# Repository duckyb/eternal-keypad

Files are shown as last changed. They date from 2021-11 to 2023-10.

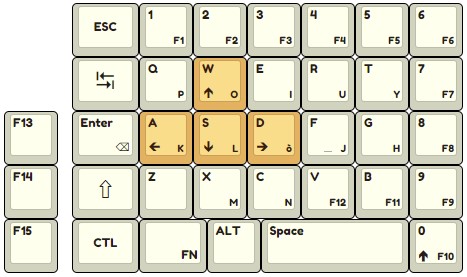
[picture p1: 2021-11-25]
gallery/default-layout.jpg

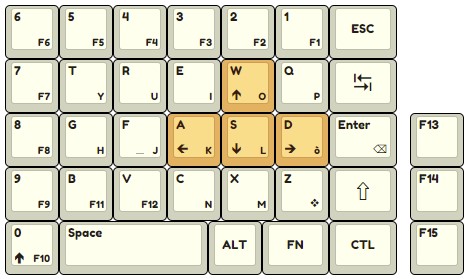
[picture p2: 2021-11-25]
gallery/lefty-layout.jpg

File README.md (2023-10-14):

# eternal_keypad_logo ETERNAL Keypad
ek-preview-rounded

<div class="shields">
  <a href="https://github.com/duckyb/eternal-keypad/releases">
    
    
  </a>
  
  <a href ="https://discord.gg/3erEKm3uht">
    
  </a>
</div>

### Sponsors

<span class="sponsors">
  <a href="https://shop.beekeeb.com/product/eternal-keypad-kit/">
    
  </a>
  <a href="https://www.pcbway.com/project/shareproject/ETERNAL_Keypad_5c58c0de.html">
    
  </a>
</span>
<div><sub>By purchasing from PCBWay I receive a percentage of the transaction</sub></div>

## Scope of the project

Eternal Keypad is an **open-source input device for gaming** that can be assembled for **both right and left hand mouse users**.

Historically there has been a scarcity of input devices for people that use their keyboard with their right hand and the mouse with the left, forcing some people to place their right hand in uncomfortable positions and/or requiring heavy remapping of in-game controls.
This device aims to fill this gap in the market that companies don't care about because the target is too small to turn a profit.

The device is Pro-micro compatible, so it's easier to build and source components.

## Features

⭕ Standard layout in a half-size form factor (all your keys are still there!)  
⭕ Ortholinear/grid layout for additional comfort  
⭕ Bluetooth support (nice!nano, battery, ZMK, power switch)  
⭕ Hotswap with Kailh Sockets  
⭕ RGB Underglow  
⭕ 3 macro buttons  
⭕ Easy to build  
⭕ Files for FR4 or laser cut plate case included  

## How can I make this?

<a href="https://youtu.be/vkTpa7AnWUo" target="_blank">
  
</a>

### Components list (latest PCB version)

#### For the Keyboard (required)

- 1× [ETERNAL Keypad PCB](https://github.com/duckyb/eternal-keypad/releases/latest)
- 36× through-hole or surface-mount diodes. (I use "1N4148 CDIL" from tme.eu)
- 36× MX style switches
- 36× Kailh Hotswap Sockets
- 1× Stabilizer (2u)
- 36× Keycaps (The set pictured above is "Honey & Milk XDA")
- 1× Microcontroller (Pro-micro or equivalent)

Optionals:
- 8× WS2812B RGB LEDs
- 1× Slider switch (for wireless)
- 1× LiPo battery (type: 301230, for wireless)

#### For the case (recommended)

- 1× [ETERNAL Keypad switch plate & bottom plate](https://github.com/duckyb/eternal-keypad/releases/latest)
  - If you want to have underglow RGB you should order a laser-cut bottom plate from acrylic, using the included `.dxf` file. If you don't care about underglow you can get an FR4 bottom plate PCB using the gerber file.
- 8× M2 Screws (I use "1154095 BOSSARD" from tme.eu)
- 4× M2 standoffs (diameter: 3mm, length: 8mm)
- 4× Rubber bump-on feet

### Buy as a DIY Kit

It might be more convenient to purchase this project as a kit, check out the [vendors page](./vendors.md).

## FAQ

Check the [dedicated page](./FAQ.md)

## Firmware

<a href="https://github.com/qmk/qmk_firmware/tree/master/keyboards/eternal_keypad" target="_blank">
  
</a>
<a href="https://www.caniusevia.com/">
  
</a>
<a href="https://zmk.dev/">
  
</a>

You can find firmwares in the [release section](https://github.com/duckyb/eternal-keypad/releases/latest), ready to download and flash.
If you want to customize them, you can do so using QMK, ZMK or VIA.

eternal_keypad

Note:
- The "A" and "D" keys are not mirrored to avoid inverting movement controls with default key-bindings.
- The "FN" key is used to access the missing half of the keyboard
- Holding the 0 key turns WASD into arrow keys

## Additional Resources

- 3D Printed case by chewiedies → [v4](https://www.thingiverse.com/thing:5329104), [v5, and v6](https://www.printables.com/model/290027-eternal-keypad-v12-gasket-mount-case-w-optional-te)

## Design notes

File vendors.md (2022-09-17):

# Vendors

This is a list of vendors that sell EK

| Store | Warehouse Location | Type | Approx. Price |
| :---: | :---: | :---: | :--: |
| [Beekeeb](https://shop.beekeeb.com/product/eternal-keypad-kit/) | Hong Kong | DIY Kit | $ 45.00 |
| [CustomKBD](https://customkbd.com/products/eternal-keypad-kit) | Australia | DIY Kit | $ 32.00 |
| [KEEBD](https://keebd.com/products/eternal-keypad-keyboard-kit) | Australia | DIY Kit | $ 40.00 |
| [PMM](https://pmm.gg/products/p-k-f-1) | Germany | Fully Assembled | € 300.00 |

💙 If you wish to profit from my project, please consider [sponsoring](https://github.com/sponsors/duckyb).

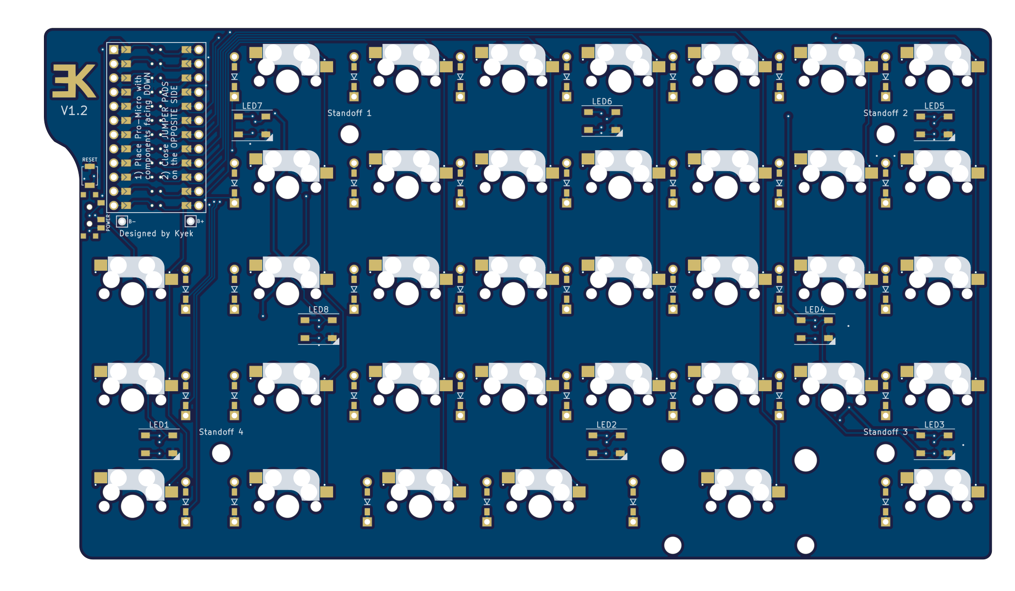
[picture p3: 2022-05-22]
pcb-kicad/front.png

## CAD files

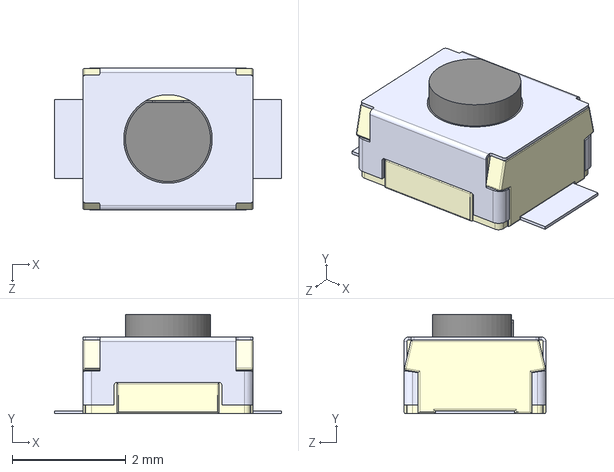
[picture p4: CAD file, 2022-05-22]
3d-models/B3U-1000P--3DModel-STEP-56544.STEP
4.00 x 1.75 x 2.50 mm

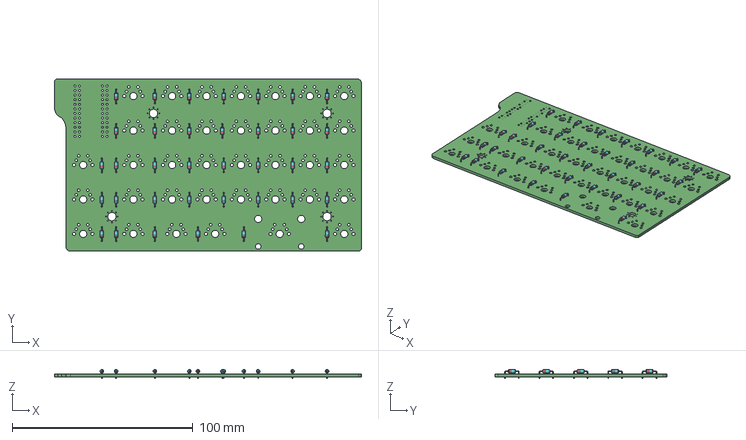
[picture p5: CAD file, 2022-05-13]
pcb-kicad/eternal-keypad.step
169.9 x 95.2 x 5.01 mm

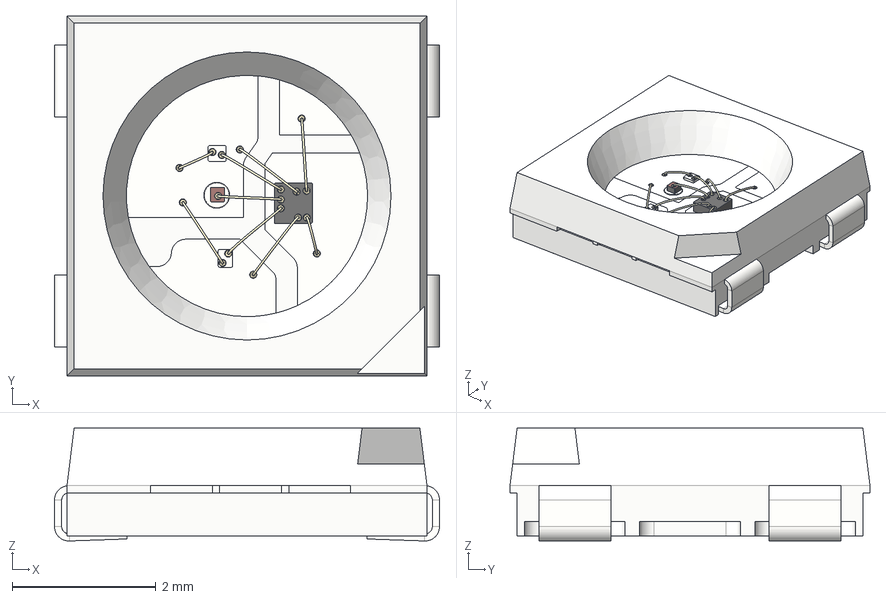
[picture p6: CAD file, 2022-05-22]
3d-models/WS2812B.step
5.35 x 5.00 x 1.57 mm

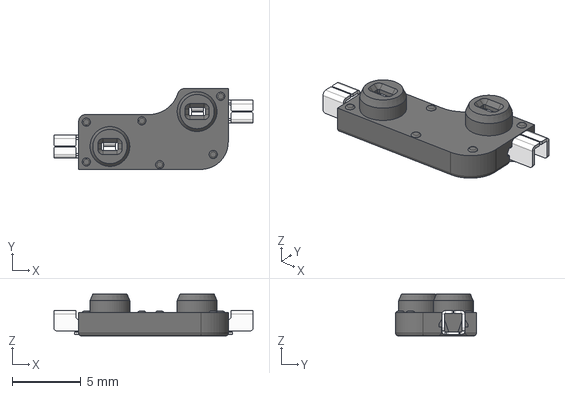
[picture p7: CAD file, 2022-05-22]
3d-models/Kailh Hotswap.step
14.5 x 5.89 x 3.05 mm
Contact x 2

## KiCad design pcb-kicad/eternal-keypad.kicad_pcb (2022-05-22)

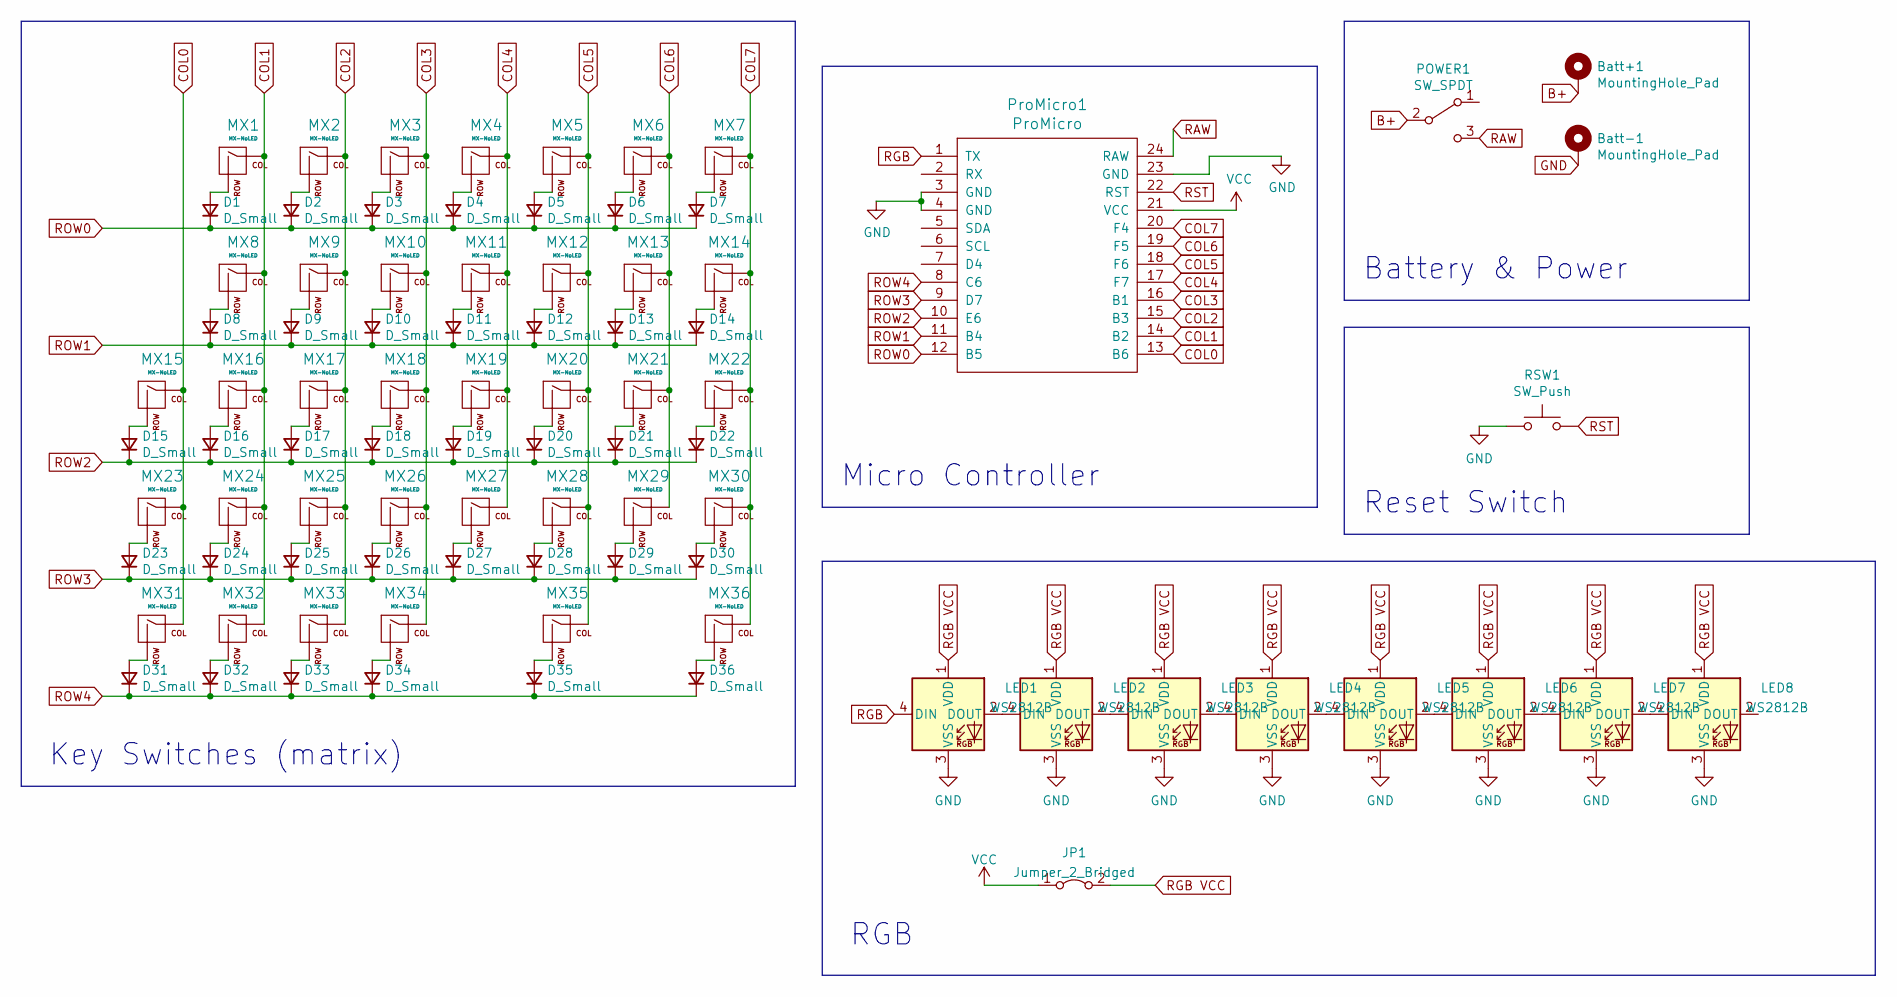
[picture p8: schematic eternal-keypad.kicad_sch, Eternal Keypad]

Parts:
Batt+1: MountingHole_Pad; 1pin_conn
Batt-1: MountingHole_Pad; 1pin_conn
D1, D2, D3, D4, D5, D6, D7, D8, D9, D10, D11, D12, D13, D14, D15, D16, D17, D18, D19, D20, D21, D22, D23, D24, D25, D26, D27, D28, D29, D30, D31, D32, D33, D34, D35, D36: D_Small; D_DO-35_SOD27_P7.62mm_Horizontal_Reversible
JP1: Jumper_2_Bridged; SolderJumper-2_P1.3mm_Bridged2Bar_RoundedPad1.0x1.5mm
LED1, LED2, LED3, LED4, LED5, LED6, LED7, LED8: WS2812B; LED_WS2812B_PLCC4_5.0x5.0mm_P3.2mm
MX1, MX8, MX16, MX24, MX32: MX-NoLED; MXOnly-1.25U-Reversible-NoLED
MX2, MX3, MX4, MX5, MX6, MX7, MX9, MX10, MX11, MX12, MX13, MX14, MX15, MX17, MX18, MX19, MX20, MX21, MX22, MX23, MX25, MX26, MX27, MX28, MX29, MX30, MX31, MX33, MX34, MX36: MX-NoLED; MXOnly-1U-Reversible-NoLED
MX35: MX-NoLED; MXOnly-3U-Reversible-ReversedStabilizers-NoLED
POWER1: SW_SPDT; SPDT_C128955
ProMicro1: ProMicro
RSW1: SW_Push; Tactile-Switch_SMT

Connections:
B+: Batt+1.1, POWER1.2 (B)
COL0: MX15.1 (COL), MX23.1 (COL), MX31.1 (COL), ProMicro1.13 (B6)
COL1: MX1.1 (COL), MX8.1 (COL), MX16.1 (COL), MX24.1 (COL), MX32.1 (COL), ProMicro1.14 (B2)
COL2: MX2.1 (COL), MX9.1 (COL), MX17.1 (COL), MX25.1 (COL), MX33.1 (COL), ProMicro1.15 (B3)
COL3: MX3.1 (COL), MX10.1 (COL), MX18.1 (COL), MX26.1 (COL), MX34.1 (COL), ProMicro1.16 (B1)
COL4: MX4.1 (COL), MX11.1 (COL), MX19.1 (COL), MX27.1 (COL), ProMicro1.17 (F7)
COL5: MX5.1 (COL), MX12.1 (COL), MX20.1 (COL), MX28.1 (COL), MX35.1 (COL), ProMicro1.18 (F6)
COL6: MX6.1 (COL), MX13.1 (COL), MX21.1 (COL), MX29.1 (COL), ProMicro1.19 (F5)
COL7: MX7.1 (COL), MX14.1 (COL), MX22.1 (COL), MX30.1 (COL), MX36.1 (COL), ProMicro1.20 (F4)
GND: Batt-1.1, LED1.3 (VSS), LED2.3 (VSS), LED3.3 (VSS), LED4.3 (VSS), LED5.3 (VSS), LED6.3 (VSS), LED7.3 (VSS), LED8.3 (VSS), ProMicro1.3 (GND), ProMicro1.4 (GND), ProMicro1.23 (GND), RSW1.1
unnamed: D1.2 (A), MX1.2 (ROW)
unnamed: D2.2 (A), MX2.2 (ROW)
unnamed: D3.2 (A), MX3.2 (ROW)
unnamed: D4.2 (A), MX4.2 (ROW)
unnamed: D5.2 (A), MX5.2 (ROW)
unnamed: D6.2 (A), MX6.2 (ROW)
unnamed: D7.2 (A), MX7.2 (ROW)
unnamed: D8.2 (A), MX8.2 (ROW)
unnamed: D9.2 (A), MX9.2 (ROW)
unnamed: D10.2 (A), MX10.2 (ROW)
unnamed: D11.2 (A), MX11.2 (ROW)
unnamed: D12.2 (A), MX12.2 (ROW)
unnamed: D13.2 (A), MX13.2 (ROW)
unnamed: D14.2 (A), MX14.2 (ROW)
unnamed: D15.2 (A), MX15.2 (ROW)
unnamed: D16.2 (A), MX16.2 (ROW)
unnamed: D17.2 (A), MX17.2 (ROW)
unnamed: D18.2 (A), MX18.2 (ROW)
unnamed: D19.2 (A), MX19.2 (ROW)
unnamed: D20.2 (A), MX20.2 (ROW)
unnamed: D21.2 (A), MX21.2 (ROW)
unnamed: D22.2 (A), MX22.2 (ROW)
unnamed: D23.2 (A), MX23.2 (ROW)
unnamed: D24.2 (A), MX24.2 (ROW)
unnamed: D25.2 (A), MX25.2 (ROW)
unnamed: D26.2 (A), MX26.2 (ROW)
unnamed: D27.2 (A), MX27.2 (ROW)
unnamed: D28.2 (A), MX28.2 (ROW)
unnamed: D29.2 (A), MX29.2 (ROW)
unnamed: D30.2 (A), MX30.2 (ROW)
unnamed: D31.2 (A), MX31.2 (ROW)
unnamed: D32.2 (A), MX32.2 (ROW)
unnamed: D33.2 (A), MX33.2 (ROW)
unnamed: D34.2 (A), MX34.2 (ROW)
unnamed: D35.2 (A), MX35.2 (ROW)
unnamed: D36.2 (A), MX36.2 (ROW)
unnamed: LED1.2 (DOUT), LED2.4 (DIN)
unnamed: LED2.2 (DOUT), LED3.4 (DIN)
unnamed: LED3.2 (DOUT), LED4.4 (DIN)
unnamed: LED4.2 (DOUT), LED5.4 (DIN)
unnamed: LED5.2 (DOUT), LED6.4 (DIN)
unnamed: LED6.2 (DOUT), LED7.4 (DIN)
unnamed: LED7.2 (DOUT), LED8.4 (DIN)
RAW: POWER1.3 (C), ProMicro1.24 (RAW)
RGB: LED1.4 (DIN), ProMicro1.1 (TX)
RGB VCC: JP1.2 (B), LED1.1 (VDD), LED2.1 (VDD), LED3.1 (VDD), LED4.1 (VDD), LED5.1 (VDD), LED6.1 (VDD), LED7.1 (VDD), LED8.1 (VDD)
ROW0: D1.1 (K), D2.1 (K), D3.1 (K), D4.1 (K), D5.1 (K), D6.1 (K), D7.1 (K), ProMicro1.12 (B5)
ROW1: D8.1 (K), D9.1 (K), D10.1 (K), D11.1 (K), D12.1 (K), D13.1 (K), D14.1 (K), ProMicro1.11 (B4)
ROW2: D15.1 (K), D16.1 (K), D17.1 (K), D18.1 (K), D19.1 (K), D20.1 (K), D21.1 (K), D22.1 (K), ProMicro1.10 (E6)
ROW3: D23.1 (K), D24.1 (K), D25.1 (K), D26.1 (K), D27.1 (K), D28.1 (K), D29.1 (K), D30.1 (K), ProMicro1.9 (D7)
ROW4: D31.1 (K), D32.1 (K), D33.1 (K), D34.1 (K), D35.1 (K), D36.1 (K), ProMicro1.8 (C6)
RST: ProMicro1.22 (RST), RSW1.2
VCC: JP1.1 (A), ProMicro1.21 (VCC)

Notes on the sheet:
Reset Switch
RGB
Battery & Power
Key Switches (matrix)
Micro Controller

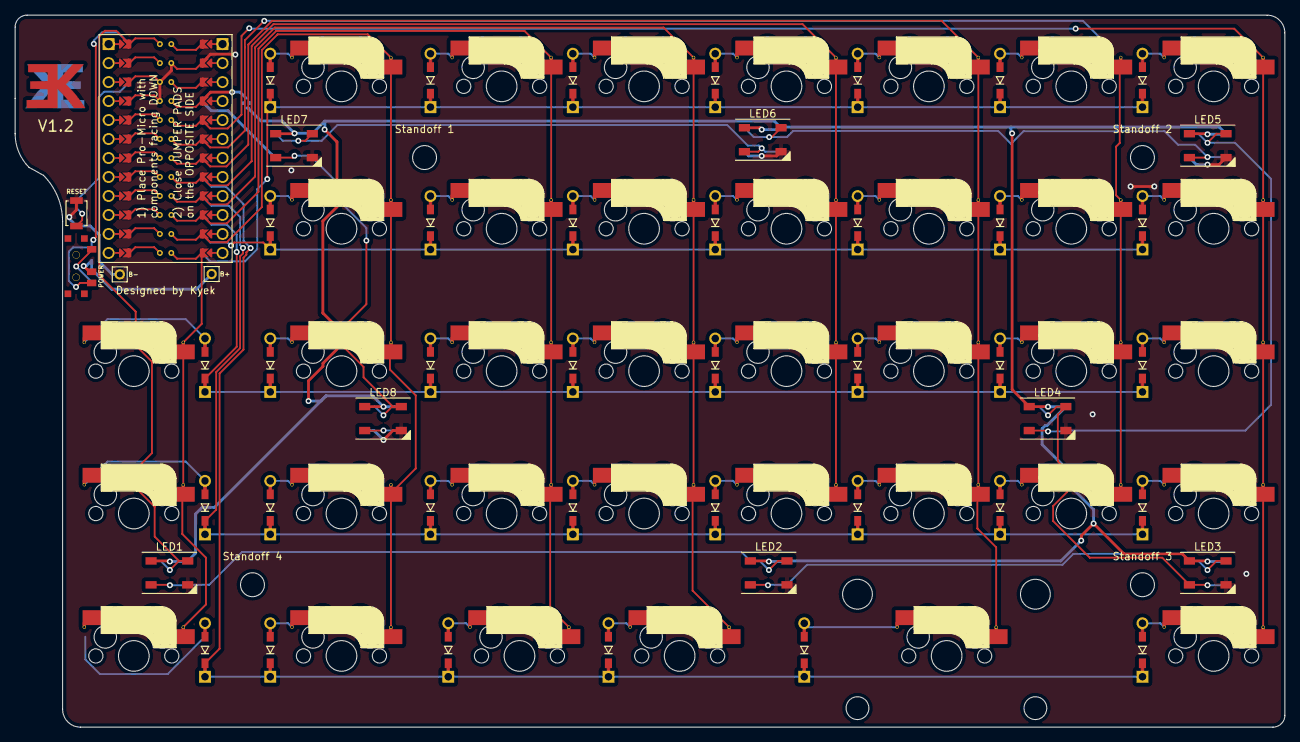
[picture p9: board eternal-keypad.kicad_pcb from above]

Board: 2 copper layers, 169.9 x 95.2 mm, 91 parts (1 on the bottom side), 63 nets.

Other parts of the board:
STAB1: Stabilizer_MX_2u
Standoff 1, Standoff 2, Standoff 3, Standoff 4: MountingHole_4.6mm_Pad_Via; MountingHole_3.2mm_M3_DIN965

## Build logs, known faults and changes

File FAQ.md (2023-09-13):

# Frequently Asked Questions

**How can I type on this keyboard?**

> *This device isn't meant for typing, think of it as a gaming controller. That's why it's called a keypad.*

**Why is the lefty layout a reversed qwerty?**

> *The mirrored layout stems from the fact that the right and left hand are "mirrored" between each other; by reflecting the keys that right-handed users press with their left hand it allows left-handed people to use the default layout and key-binding of games and the same hand-movements (specular) that right-handed people normally use.*

**Is there a version for right-handed people? Is the PCB reversible?**

> *Yes, you can assemble all components on the opposite side of the PCB as well as the case plates, and use the default layout. The result will be a device that you can use with your left hand. (regular qwerty layout)*

**What games can I play with it?**

> *It can work for any game, but it works best with first-person or third-person games.
I do not recommend it for games where you don't use the mouse (both hands on the keyboard).*

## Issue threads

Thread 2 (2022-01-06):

Blank plates

duckyb, 2022-01-06:
I designed the device with the pattern that I selected and I wish to keep that as the default, so I will not include blank plates in the releases for the time being.

Since it's an easy change, you can remove the pattern by yourself or request the blank plates here instead.

duckyb, 2022-01-06:
## v1.0

[blank_bottom_gerber.zip](https://github.com/duckyb/eternal-keypad/files/7823476/blank_bottom_gerber.zip)
[blank_plate_gerber.zip](https://github.com/duckyb/eternal-keypad/files/7823477/blank_plate_gerber.zip)

Closed 2022-05-11.

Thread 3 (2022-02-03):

[Switch Plate] Cannot manufacture due to "small bridges"

duckyb, 2022-02-03:
> Hi Sir , Please kindly note that the space between with these slots need 4mm at least as below arrow ,which will break off easily in the production , so that we will cancel it and then you will modify it and then to replace the correct one ,thanks
-- JLCPCB

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

---

[Original post by r/jammer-hammer](https://www.reddit.com/r/MechanicalKeyboards/comments/rag46p/comment/hvfrk2r/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)

duckyb, 2022-02-03:
I am considering increasing the edge thickness for the next version; but this would mean that the previous PCB / Plate files will be incompatible with this new version. (It will be possible to assemble but the edges won't match)

It might be a good idea to release a v1.1 with the new features and old edge, to maintain backward compatibility, and after that release v2.0 with the new features and new edge.

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

duckyb, 2022-04-28:
I have decided to not increase the outer edge. If JLC doesn't want to print it you can try another printing service like allpcb or pcbway or you can laser cut it from a metal sheet using the DXF file.

Closed 2022-04-28.

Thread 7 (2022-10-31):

No Left handed LAYOUT in QMK

vryken, 2022-10-31:
I was trying to make a custom keymap for the Lefty config on the eternal keypad. The basic lefty firmware will not work for my needs. Anywhere  I can get a lefty LAYOUT? Keymap.c for lefty is still in the default config and QMK Configurator and VIA are as well. Any thoughts? Thanks in advance. Sadly, everything is soldered already so to flip it would be a massive pain.

duckyb, 2022-10-31:
The layout is configured for people that use the keymap with their left hand and mouse with the right.
However, you can still configure and flash keymaps based on this layout on the lefty keypad.

When configuring the firmware, simply consider that everything will be mirrored on your device.

vryken, 2022-10-31:
Thanks! I made some solder mistakes so have to buy another board but really like the format. Appreciate all the work on it.

duckyb, 2022-10-31:
@vryken are you sure that you can't fix it? Contact me on discord if you need some help with it

Closed 2022-10-31.

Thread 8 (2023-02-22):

Tricky soldering with new Kailh MX Sockets

hmngwy, 2023-02-22:
The new Kailh MX sockets have this reinforced back solder pad, when you try to solder it in, because of the required angle to reach the socket's pad, you may end up accidentally hitting a diode's joint if they're already soldered in.

For new builds this can be avoided by soldering sockets first before diodes, however, if you end up needing to fix a socket's pad with a diode already present next to it you may encounter this issue.

Moving the diode on the Y axis may also help this issue.

duckyb, 2023-02-22:
Can you share a link to this kind of sockets? I'm unfamiliar

hmngwy, 2023-03-04:
> Can you share a link to this kind of sockets? I'm unfamiliar

http://m.kailhswitch.com/mechanical-keyboard-switches/box-switches/kailh-new-mx-hot-swap-socket.html

mferfe8, 2025-05-13:
I need the .ino file, but the keyboard shortcut only shows the .hex file. Where or how can I get the .ino file?

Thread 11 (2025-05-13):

Looking for firmware source code

mferfe8, 2025-05-13:
Thank you very much for your contribution regarding the keyboard. I've made it for both right- and left-handed users.
I need the .ino file, which I've lost.
Can you provide it?
Thank you.

mferfe8, 2025-05-13:
The link only has the .hex but I need the .ino (for a presentation)

duckyb, 2025-05-13:
Thank you for opening an issue here.

I believe the `.ino` file format is the file format that is uses to flash Arduino boards. In this case we are not using an Arduino board and we need to flash the firmware using QMK directly or flashing a `firmware.hex` file using QMK Toolbox.

Source: https://docs.qmk.fm/newbs_flashing

mferfe8, 2025-05-13:
Thanks for your help, but I don't know how to do it, not even through the link. I'm really clumsy. Could you send me the flashed link?

duckyb, 2025-05-13:
Is your current objective to flash the keyboard with it's firmware?
What operating system are you using?
Which micro-controller board did you install on the keyboard?

It will be very hard for me to provide better instructions than what you can find here: https://docs.qmk.fm/newbs_flashing#flashing-your-keyboard-with-qmk-toolbox

I recommend following the guide from the section "flashing-your-keyboard-with-qmk-toolbox". If you need further help with this I would recommend joining the QMK discord chat.

mferfe8, 2025-05-13:
I'm using Windows, and the board I used for the keyboard is the Arduino Micro. I need to show the code for a presentation, but I don't have it, and I've only seen the .hex file, which isn't useful because I don't know how it works.

duckyb, 2025-05-13:
The `firmware.hex` file is built from C code which you can find here: https://github.com/qmk/qmk_firmware/tree/master/keyboards/eternal_keypad

This is probably the specific file you're trying to look at: https://github.com/qmk/qmk_firmware/blob/6b1a376aee93c74a0445d918e49c9118c59616fd/keyboards/eternal_keypad/keymaps/default/keymap.c

mferfe8, 2025-05-13:
Thank you very much, I'll try the second link to see if I know how to do something, I'll let you know.

mferfe8, 2025-05-23:
Hello,
I have not yet presented it, it is to prepare the final project of
electronic maintenance grade. When I finish it, I send you a copy.
Thank you

El vie, 23 may 2025, 9:41, Duccio ***@***.***> escribió:

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

Closed 2025-05-14.

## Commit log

2021-10-13 Create project
    [flippable-gamepad.kicad_pcb, flippable-gamepad.sch]
2021-10-13 Test schematic ready
    [flippable-gamepad.sch]
2021-10-13 Add ProMicro footprints
    [flippable-gamepad.sch]
2021-10-14 Non flippable version test
    [flippable-gamepad.kicad_pcb, flippable-gamepad.sch]
2021-10-14 Fresh start
    [flippable-gamepad.kicad_pcb, flippable-gamepad.sch]
2021-10-14 Update silkscreen
    [flippable-gamepad.kicad_pcb]
2021-10-15 Front silk screen
    [flippable-gamepad.kicad_pcb]
2021-10-15 Rename project to Eternal Keypad
    [eternal-keypad.kicad_pcb, eternal-keypad.sch]
2021-10-16 First prototype ready
    [eternal-keypad.kicad_pcb, eternal-keypad.sch]
2021-10-17 Update PCB and add firmware
    [eternal-keypad.kicad_pcb]
2021-10-17 Update preview and fill zone
    [eternal-keypad.kicad_pcb]
2021-11-14 Add plates and bump version
    [eternal-keypad-bottom.kicad_pcb, eternal-keypad-plate.kicad_pcb, eternal-keypad.kicad_pcb]
2021-11-14 Final adjustments and case patterns
    [eternal-keypad-bottom.kicad_pcb, eternal-keypad-plate.kicad_pcb, eternal-keypad.kicad_pcb]
2021-11-14 Remove unused footprints
2021-11-14 Rearrange repository files
    [eternal-keypad-bottom.kicad_pcb, eternal-keypad-plate.kicad_pcb, eternal-keypad.kicad_pcb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]
2022-05-13 Publish v1.1
    [eternal-keypad.kicad_pcb, eternal-keypad.kicad_sch, eternal-keypad.step]
2022-05-13 Remove recommended standoffs from README
2022-05-14 Add power, reset, RGB Cutoff, Battery Pads
    [eternal-keypad.kicad_pcb, eternal-keypad.kicad_sch]
2022-05-17 Update plates to Kicadv6
    [eternal-keypad-bottom.kicad_pcb, eternal-keypad-plate.kicad_pcb]
2022-05-17 Update board constraints
    [eternal-keypad.kicad_pcb, eternal-keypad.sch]
2022-05-22 Add 3D models
    [B3U-1000P--3DModel-STEP-56544.STEP, Kailh Hotswap.step, WS2812B.step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]
2022-11-10 Add PCBWay sponsor
2023-09-13 docs: add v6 version of the case
